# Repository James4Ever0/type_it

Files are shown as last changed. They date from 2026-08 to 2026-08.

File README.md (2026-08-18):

# Type It — Macro Keyboard

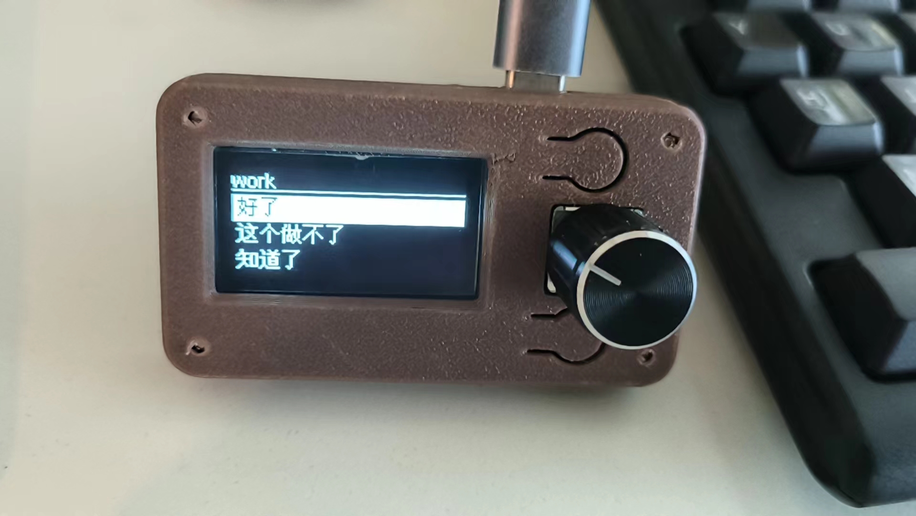
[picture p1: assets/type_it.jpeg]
Type It — Macro Keyboard


A pocket macro keyboard for the snippets you type over and over: chat replies,
work responses, template text. Turn the knob, pick a snippet, and it is sent —
as real USB HID keystrokes on the hardware, or straight to your clipboard in
the desktop demos.

Three interchangeable front-ends share one data model: a **profile** is a
`.txt` file whose non-empty lines are **candidates**, and everything re-sorts
by **most-recently-used**.

| Component | What it is | Docs |
|---|---|---|
| [`hardware/`](hardware/) | RP2040 Zero firmware + enclosure, types over USB HID | [hardware/README.md](hardware/README.md) |
| [`software/golang/`](software/golang/) | Go/Ebiten desktop demo → clipboard | [software/golang/README.md](software/golang/README.md) |
| [`software/python/`](software/python/) | pygame desktop demo → clipboard | [software/python/README.md](software/python/README.md) |

## Quick start

- **Hardware** — wire per [`hardware/WIRING.md`](hardware/WIRING.md), install
  the toolchain per [`hardware/DEPENDENCIES.md`](hardware/DEPENDENCIES.md),
  upload [`hardware/type_it/`](hardware/type_it/).
- **Go demo** — `cd software/golang && ./compile.sh && ./type_it`
- **Python demo** — `cd software/python && pip install -r requirements.txt && python main.py`

## Shared interaction model

- Turn the knob (or scroll) to move the highlight.
- Short-press to open a profile / type or copy a candidate.
- Long-press to go back.

## Repository layout

```text
.
├── hardware/              # RP2040 firmware, wiring, enclosure
│   ├── type_it/           # Arduino sketch
│   ├── casing/            # 3D-printable enclosure
│   ├── WIRING.md
│   └── DEPENDENCIES.md
├── software/
│   ├── golang/            # Ebiten desktop demo
│   └── python/            # pygame desktop demo
└── README.md
```

## License

Released into the public domain under the [Unlicense](https://unlicense.org).
See [`LICENSE`](LICENSE).

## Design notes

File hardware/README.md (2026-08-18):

# Type It Hardware — RP2040 Zero Macro Keyboard

A physical macro keyboard: a Waveshare **RP2040 Zero** running Arduino
firmware, a 1.3" **SH1106 128×64 I2C OLED**, and an **EC11 rotary encoder**
with push switch. Pick a profile, turn the knob, and the selected snippet is
typed into the focused application as real USB HID keystrokes.

It is the hardware counterpart of the desktop demos in
[`software/`](../software/) — all three share the same
profiles/candidates/recency model.

## Components

| Part | Role |
|---|---|
| Waveshare RP2040 Zero | MCU, USB HID keyboard |
| 1.3" SH1106 128×64 I2C OLED | Menu display, CJK-capable |
| EC11 rotary encoder | Scroll / confirm / long-press back |
| CON / BAK buttons | Optional confirm / back buttons |

## Repository layout

- [`type_it/`](type_it/) — Arduino sketch (`type_it/type_it.ino`)
- [`DEPENDENCIES.md`](DEPENDENCIES.md) — Arduino core + library install, board setup, upload
- [`WIRING.md`](WIRING.md) — GPIO pin map and step-by-step wiring guide
- [`casing/`](casing/) — 3D-printable enclosure (`.3mf`)
- [`assets/`](assets/) — wiring reference photo

## Quick start

1. Wire the module — see [`WIRING.md`](WIRING.md) (GPIO table, pull-ups,
   encoder direction, I2C address).
2. Install the toolchain — see [`DEPENDENCIES.md`](DEPENDENCIES.md).
3. Open `type_it/type_it.ino` and upload (Arduino IDE or `arduino-cli`).
4. Open the serial monitor at **115200 baud** and send `HELP` for the full
   command list.

## Firmware highlights

- **Profiles on LittleFS** — every `.txt` in `/profiles` is a profile; each
  non-empty line is a type-able candidate.
- **Recency ordering** — profiles and candidates re-sort by last use and the
  order survives reboots (stored in `/usage.dat`).
- **USB HID typing** — ASCII types directly; Unicode/CJK types per host
  method (Linux IBus, macOS Unicode Hex Input, Windows Alt+Numpad). Switch
  host behavior with `SETOS:lin|mac|win` or the Settings menu.
- **CJK display** — the SH1106 is rendered with the U8g2 `wqy12` GB2312 font.
- **Serial management** — create/rename/delete profiles and edit candidates
  over serial (`SETTEXT:profile <<EOF … EOF`, `APPEND`, `LIST`, …).
- **Diagnostics** — `DIAG` runs a 7-step self-test (display, encoder,
  buttons, OS typing, filesystem, EEPROM, font).
- **Resume state** — the last view and selection are restored from EEPROM on
  power-up.

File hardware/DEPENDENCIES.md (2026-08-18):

# Dependencies — Type It Macro Keyboard

## Required software

1. **Arduino IDE** 1.8.x or 2.x, or **Arduino CLI**
2. **Earle Philhower Arduino-Pico core** (supports RP2040/RP2350 boards with USB and LittleFS)
3. **U8g2 library** by Oliver Kraus (SH1106 display driver)

## Required hardware

- 1.3 Inch TFT OLED display with EC11 rotary encoder board (IIC interface)

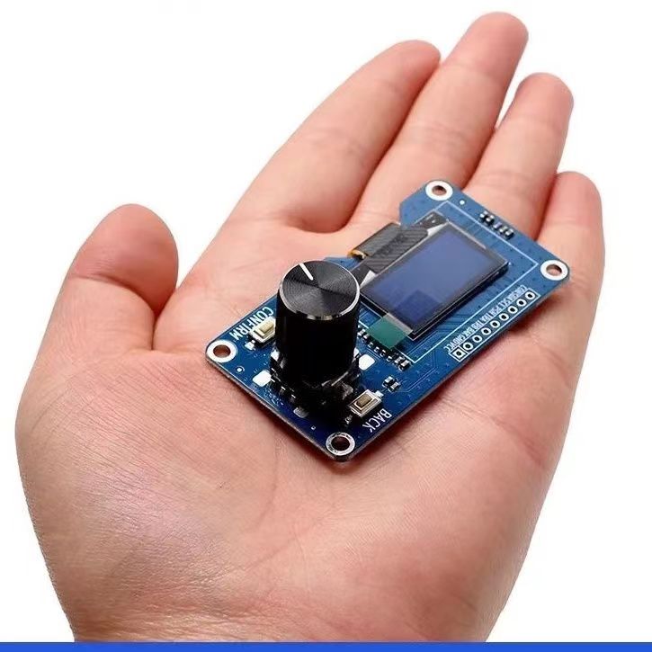
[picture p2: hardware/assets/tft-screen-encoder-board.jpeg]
TFT Screen Encoder Board (https://mobile.yangkeduo.com/goods.html?ps=Z3C52HupHn)


- RP2040-Zero microcontroller board

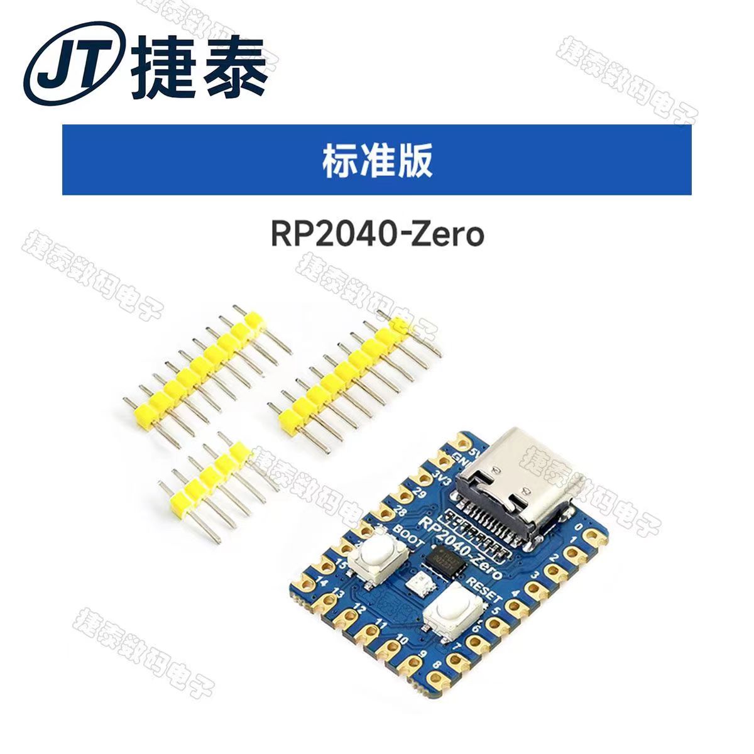
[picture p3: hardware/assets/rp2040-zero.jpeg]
RP2040-Zero (https://mobile.yangkeduo.com/goods.html?ps=jFZypVHLIi)


## Arduino-Pico core installation

### Arduino IDE 2.x

1. Open **File > Preferences**.
2. In **Additional boards manager URLs**, add:
   ```text
   https://github.com/earlephilhower/arduino-pico/releases/download/global/package_rp2040_index.json
   ```
3. Open **Tools > Board > Boards Manager**.
4. Search for **"Raspberry Pi Pico/RP2040"** by Earle F. Philhower, III.
5. Install the latest version.

### Arduino CLI

```bash
arduino-cli config add board_manager.additional_urls https://github.com/earlephilhower/arduino-pico/releases/download/global/package_rp2040_index.json
arduino-cli core update-index
arduino-cli core install rp2040:rp2040
```

## U8g2 library installation

### Arduino IDE

1. Open **Tools > Manage Libraries...**.
2. Search for **"U8g2"** by Oliver Kraus.
3. Install the latest version.

### Arduino CLI

```bash
arduino-cli lib install "U8g2"
```

## Board selection

Select the board that matches your hardware. For the Waveshare RP2040 Zero:

- **Board**: *Raspberry Pi Pico / RP2040 > Waveshare RP2040 Zero*
- **USB Stack**: *Adafruit TinyUSB* (recommended; required for `Keyboard.h` and USB-CDC Serial)
- **Flash Size**: choose a split that leaves room for a filesystem, e.g. *2 MB (Sketch: 1 MB, FS: 1 MB)* or larger

If your exact board is not listed, use **"Raspberry Pi Pico"** and set the correct USB stack and flash size.

## Build and upload

### Arduino IDE

1. Open `hardware_project/type_it/type_it.ino`.
2. Select the board and port as described above.
3. Click **Upload**.

### Arduino CLI

From the `hardware_project` directory:

```bash
arduino-cli compile --fqbn rp2040:rp2040:waveshare_rp2040_zero type_it
arduino-cli upload --fqbn rp2040:rp2040:waveshare_rp2040_zero -p /dev/ttyACM0 type_it
```

Replace `/dev/ttyACM0` with the actual serial port of your RP2040 Zero.

## First use

1. Open the **Serial Monitor** at **115200 baud**.
2. The firmware prints a startup banner and the number of stored profiles.
3. Type `HELP` and press Enter to see the available serial commands.

Example: create a profile and upload multiline text

```text
ADDPROFILE:work
OK created work

SETTEXT:work <<EOF
Hello, world!
Thanks,
Me
EOF
OK replaced work (29 bytes)

LIST
Profiles:
  work (3 items)
```

## Notes and limitations

- **HID typing**: `Keyboard.print()` sends raw keycodes. ASCII/Latin-1 text works reliably. Typing CJK or other multi-byte Unicode characters is not supported by the standard Arduino `Keyboard` library; such text can be stored and viewed on the display but will not type correctly through USB HID.
- **Display font**: The default font is `u8g2_font_7x14_tf` for the header and `u8g2_font_6x13_tf` for list items. If you need CJK glyphs on the display, replace these with a U8g2 CJK font (e.g., `u8g2_font_unifont_t_chinese2`) and note that the larger font may reduce the number of visible lines.
- **Filesystem wear**: Every type action writes the usage-order file to LittleFS. For heavy daily use, consider periodically backing up profiles via `VIEW:profile` and rebuilding the device rather than relying on the flash for indefinite high-frequency writes.

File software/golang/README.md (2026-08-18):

# Type It Go — Desktop Demo (Ebiten)

A Go/[Ebiten](https://ebitengine.org/) simulation of the macro keyboard: it
renders the LED display and knob, reads the same `./profiles` text files as
the firmware, and copies the selected candidate to the system clipboard.

## Requirements

- Go 1.22+
- Linux: X11 development headers (Ebiten dependency):

  ```bash
  sudo apt-get install -y libxrandr-dev libxcursor-dev libxinerama-dev libxi-dev libgl1-mesa-dev libxxf86vm-dev
  ```

## Build & run

```bash
./compile.sh     # checks X11 headers, go mod tidy, builds ./type_it
./type_it        # or: go run .
```

`./test.sh` runs `go vet`, builds, and — when `xvfb-run` is available —
smoke-runs the app headless for 2 seconds.

## Controls

| Input | Action |
|---|---|
| ↑ / W | Scroll up |
| ↓ / S | Scroll down |
| → / Enter / Space | Open profile / copy candidate |
| ← / Esc / Backspace | Go back |
| Q | Save & quit |
| Mouse wheel | Scroll |
| Drag on the knob | Scroll |
| Click on the knob | Press (long press = back) |

## Profiles

One profile = one `.txt` file in `./profiles/`. The file name is the profile
name; each non-empty, trimmed line is a candidate; duplicate lines are
collapsed.

```text
# profiles/work.txt
知道了
ok
这个做不了
```

Profiles and candidates are sorted most-recently-used first; the ordering is
persisted to `./usage.json` and restored on start.

## Files

- `main.go` — the entire demo (single file)
- `compile.sh`, `test.sh` — build / smoke-test helpers
- `profiles/` — user profile content
- `usage.json` — runtime state, regenerated automatically

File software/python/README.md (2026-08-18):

# Type It Python — Desktop Demo (pygame)

A [pygame](https://www.pygame.org/) simulation of the macro keyboard: it
renders the LED display and knob, reads the same `./profiles` text files as
the firmware, and copies the selected candidate to the clipboard.

## Requirements

- Python 3.10+
- Linux/X11: `wmctrl` (optional — keeps the window always-on-top)

## Install & run

```bash
pip install -r requirements.txt
python main.py
```

## Controls

| Input | Action |
|---|---|
| ↑ / W | Scroll up |
| ↓ / S | Scroll down |
| → / Enter / Space | Open profile / copy candidate |
| ← / Esc / Backspace | Go back |
| Q | Save & quit |
| Mouse wheel | Scroll |
| Drag on the knob | Scroll |
| Click on the knob | Press (long press = back) |

## Profiles

Same format as the Go demo and the firmware: one `.txt` file per profile in
`./profiles/`, each non-empty line is a candidate. Recency ordering **and**
the last-viewed UI state are persisted to `./usage.json` and restored on
start.

## Notes

- A CJK-capable system font is picked automatically for headers and list
  items, with a DejaVu fallback.
- On Linux the window is raised above others via `wmctrl` when available.

## Files

- `main.py` — the entire demo (single file)
- `requirements.txt` — pygame, pyperclip
- `profiles/` — user profile content
- `usage.json` — runtime state, regenerated automatically

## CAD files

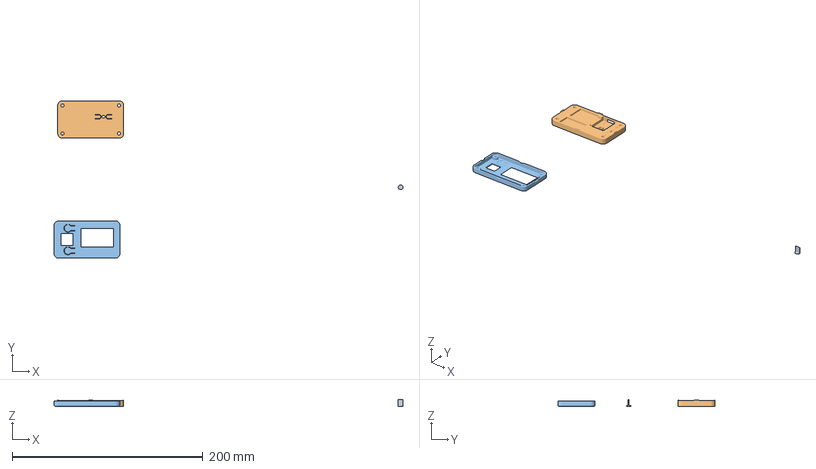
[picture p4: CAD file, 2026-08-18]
hardware/casing/ec11_rp2040_macro_keyboard_v2.3mf
365.6 x 165.0 x 7.00 mm
encoder_filter.stl
bottom_casing_with_wire_slot_and_screw_sink_v2_unfixed_fixed.stl_Boolean
Oled_EC11_Encoder_Case-Main.step_Boolean_Boolean_Boolean_Boolean

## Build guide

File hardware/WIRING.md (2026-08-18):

# Wiring Guide — Type It Macro Keyboard

This document describes how to connect the RP2040 Zero to the SH1106 I2C display + rotary encoder module described in `pinouts.txt`.

## Parts

- **MCU**: Waveshare RP2040 Zero (or any RP2040 board with the same GPIO labels)
- **Display / input module**: 1.3" SH1106 128×64 I2C OLED + EC11 rotary encoder + CON/BAK buttons
  - Connector labels from `pinouts.txt`: `CON, SDA, SCL, PSH, TRA, TRB, BAK, GND, VCC`
- **Breadboard and jumper wires** (or a custom PCB)

## Default GPIO mapping

The firmware uses the following RP2040 Zero GPIO pins by default. They are grouped together so you can use one side of the board for the whole module.

| Module pin | Function | RP2040 Zero GPIO | Note |
|---|---|---|---|
| VCC | 3.3 V power | 3V3 | Do **not** connect to 5 V |
| GND | Ground | GND | |
| SDA | I2C data | GP4 | `PIN_SDA` in `type_it.ino` |
| SCL | I2C clock | GP5 | `PIN_SCL` in `type_it.ino` |
| TRA | Encoder A phase | GP3 | `PIN_ENC_A` in `type_it.ino` |
| TRB | Encoder B phase | GP2 | `PIN_ENC_B` in `type_it.ino` |
| PSH | Encoder push switch | GP6 | `PIN_ENC_SW` in `type_it.ino` |
| CON | Confirm button | GP14 | `PIN_CON` in `type_it.ino` **(optional)** |
| BAK | Back button | GP15 | `PIN_BAK` in `type_it.ino` **(optional)** |

> The exact GPIO numbers are arbitrary — any digital GPIO can be used for the buttons and encoder, and any I2C-capable GPIO pair can be used for SDA/SCL. If you change the wiring, update the `#define PIN_...` lines at the top of `type_it/type_it.ino`.

## Minimal wiring (encoder push switch only)

If you only want the rotary encoder's built-in push switch and do not wire the separate `CON`/`BAK` buttons, change the top of `type_it.ino` to:

```cpp
#define PIN_CON   -1
#define PIN_BAK   -1
```

With this setup the encoder switch does everything:

| Action | How |
|---|-----|
| Confirm / open profile / type candidate | Short press the encoder knob |
| Go back | Long-press the encoder knob (> 600 ms) |

## Wiring tutorial

<!-- a picture showing actual wiring -->

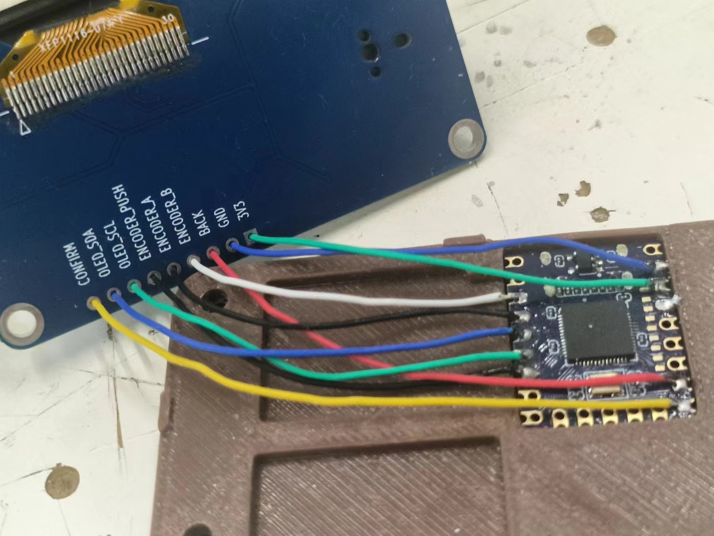
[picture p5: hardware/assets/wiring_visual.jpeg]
A picture showing actual wiring


Thin wires stripped from common data cabling are sufficient.

Step-by-step guide:

- Strip and pre-solder the wire coils before inserting them into the RP2040 solder holes.
- Optionally, use tape or heavy objects, or combine tape with thin plates, to hold the coils in place before soldering.
- Solder the coils onto the RP2040 board.
- Insert the coils into the corresponding holes on the display board.
- Pull the coils taut so the display board can be pushed down into place, close enough for the enclosure to be assembled.
- Use tape to hold the display in place.
- Cut off excess wire length, leaving at most 1 cm per wire.
- Use a soldering iron to heat the insulation of each wire and strip it off manually.
- Solder each wire into its corresponding hole on the display board.
- Trim any excess coil length.
- Remove the tape and assemble the enclosure.

## Pull-ups

- The firmware configures `INPUT_PULLUP` for all button and encoder pins. No external pull-up resistors are required for the switches or encoder A/B pins.
- The SH1106 module usually includes its own I2C pull-up resistors. If your module does not, add 4.7 kΩ pull-ups from SDA and SCL to 3.3 V.

## Encoder direction

If turning the knob clockwise moves the highlight **up** instead of **down**, swap the `PIN_ENC_A` and `PIN_ENC_B` definitions (or physically swap the `TRA` and `TRB` wires).

## I2C address

The default SH1106 I2C address is `0x3C`. If the display stays black after upload:

1. Check the module documentation for the correct address (some modules use `0x3D`).
2. If you need `0x3D`, change the U8g2 constructor in `type_it.ino` from:
   ```cpp
   U8G2_SH1106_128X64_NONAME_F_HW_I2C u8g2(U8G2_R0, U8G2_PIN_NONE);
   ```
   to:
   ```cpp
   U8G2_SH1106_128X64_NONAME_F_HW_I2C u8g2(U8G2_R0, U8G2_PIN_NONE, /* SCL */ PIN_SCL, /* SDA */ PIN_SDA, /* reset */ U8G2_PIN_NONE);
   u8g2.setI2CAddress(0x3D * 2);
   ```

## Physical layout tips

- Keep the I2C wires (SDA/SCL) short and twisted if possible to reduce noise.
- The encoder A/B wires can pick up noise; if you see erratic scrolling, add 100 nF ceramic capacitors from each encoder pin to GND, or reduce the wire length.
- The RP2040 Zero is 3.3 V only. Do not connect 5 V logic signals to the GPIO pins.

## Next steps

After wiring, follow `DEPENDENCIES.md` to install the required Arduino libraries and upload the firmware.

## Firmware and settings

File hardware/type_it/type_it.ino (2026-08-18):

/*
 * type_it — Macro Keyboard Firmware for RP2040 Zero
 *
 * A hardware port of ../main.py's profile/candidate macro keyboard.
 *
 * Hardware:
 *   - RP2040 Zero
 *   - 1.3" SH1106 128x64 I2C OLED
 *   - EC11 rotary encoder (TRA=A, TRB=B, PSH=push switch)
 *   - CON (KEY1) confirm button
 *   - BAK (KEYO) back button
 *
 * UX:
 *   - Encoder turn                    -> scroll highlight
 *   - Encoder short press / CON        -> open profile, select menu item, or type candidate
 *   - Encoder long press / BAK         -> go back; from Profiles opens the master menu
 *   - CON mirrors the encoder short press; BAK mirrors the encoder long press
 *   - Master menu (long press from Profiles):
 *       Profiles, Diagnostic, Settings, Stats, About, Help
 *   - Last-used ordering is persisted across reboots
 *
 * Serial commands (115200 baud, CRLF or LF terminated):
 *   SETTEXT:profile <<EOF     replace profile with a block of text
 *   APPENDTEXT:profile <<EOF  append a block of text to profile
 *   APPEND:profile text       append a single line to profile
 *   SETLINE:profile:n text    set/replace candidate at line n (1-based)
 *   ADDPROFILE:profile        create a new empty profile
 *   DELPROFILE:profile        delete a profile
 *   RENAME:old new            rename a profile
 *   DELLINE:profile:n         delete candidate at line n
 *   LIST                      list all profiles
 *   VIEW:profile              view profile contents
 *   INFO                      show version and state
 *   SETOS:lin|mac|win         set host OS for Unicode typing
 *   GETOS                     show current host OS
 *   DIAG                      enter interactive diagnostic mode
 *   HELP                      command summary
 *   RESET                     factory reset
 *
 * Heredoc-style markers are optional; if omitted, the literal string "EOF"
 * ends the upload (only useful for interactive terminals).
 */

#include <Keyboard.h>
#include <Wire.h>
#include <U8g2lib.h>
#include <LittleFS.h>
#include <EEPROM.h>
#include <vector>
#include <algorithm>
#include <cstring>
#include <cctype>

// ==================== Pin assignments (RP2040 Zero GPIO) ====================
#define PIN_SDA           4   // OLED SDA  (I2C0)
#define PIN_SCL           5   // OLED SCL  (I2C0)
#define PIN_ENC_A         3   // EC11 A phase (TRA)
#define PIN_ENC_B         2   // EC11 B phase (TRB)
#define PIN_ENC_SW        6   // EC11 push switch (PSH)
#define PIN_CON           14 // Confirm button (KEY1) — optional, set to -1 to disable
#define PIN_BAK          15   // Back button (KEYO) — optional, set to -1 to disable

// ==================== Constants ====================
#define FW_VERSION        0x02
#define EEPROM_SIZE       512
#define SERIAL_BAUD       115200
#define SERIAL_TIMEOUT_MS 1500

#define LONG_PRESS_MS     600
#define DEBOUNCE_MS       25
#define FLASH_MS          800
#define KNOB_STEP_MS      120   // minimum ms between highlight moves via encoder

#define ENCODER_PULSES_PER_DETENT 4
#define MAX_PROFILE_NAME  32
#define MAX_LINE_LEN      256
#define MAX_VISIBLE       3
#define HEADER_H          14
#define LINE_H            15
#define SCREEN_W          128
#define SCREEN_H          64

#define VERBOSE_SERIAL    1       // set to 0 to disable runtime Serial logging

#if VERBOSE_SERIAL
  #define DBG(x) do { if (VERBOSE_SERIAL) Serial.println(x); } while(0)
#else
  #define DBG(x)
#endif

// CJK font. Largest single-font Simplified Chinese coverage available in u8g2.
// Requires u8g2.drawUTF8() / u8g2.getUTF8Width() and u8g2.enableUTF8Print().
#define CJK_FONT u8g2_font_wqy12_t_gb2312

#define PROFILES_DIR      "/profiles"
#define USAGE_PATH        "/usage.dat"

// ==================== EEPROM layout ====================
#define ADDR_MAGIC        0
#define ADDR_VIEW         1
#define ADDR_PROF_IDX_LO  2
#define ADDR_PROF_IDX_HI  3
#define ADDR_CAND_IDX_LO  4
#define ADDR_CAND_IDX_HI  5
#define ADDR_OS_MODE      6
#define ADDR_RESERVED     7

// ==================== U8g2 display object ====================
U8G2_SH1106_128X64_NONAME_F_HW_I2C u8g2(U8G2_R0, U8X8_PIN_NONE);

// ==================== Data model ====================
struct Candidate {
  String text;
  uint32_t order;
};

struct Profile {
  String name;
  uint32_t order;
  std::vector<Candidate> candidates;
};

struct UsageEntry {
  char type;      // 'P' or 'C'
  String key;     // profile name OR "profile::candidate"
  uint32_t order;
};

// ==================== Runtime state ====================
std::vector<Profile> profiles;
std::vector<UsageEntry> usage;

String view = "profiles";       // "profiles" | "candidates" | "master" | "settings" | "stats" | "about" | "help"
int profileIndex = 0;
int candidateIndex = 0;
int masterIndex = 0;
int settingsIndex = 0;
int statsScroll = 0;
int helpScroll = 0;

// Scroll window offsets for cursor-based list scrolling
int profileListOffset = 0;
int candidateListOffset = 0;
int masterListOffset = 0;
int settingsListOffset = 0;
int statsListOffset = 0;
int helpListOffset = 0;

uint32_t nextOrder = 1;
bool needsRedraw = true;

// Host OS mode for Unicode typing
enum OSMode { OS_LIN = 0, OS_MAC = 1, OS_WIN = 2 };
const char* OSModeNames[] = {"lin", "mac", "win"};
OSMode osMode = OS_LIN;

// Diagnostic mode state
enum DiagState {
  DIAG_INTRO,
  DIAG_DISPLAY_TEST,
  DIAG_ENCODER_TEST,
  DIAG_BUTTON_TEST,
  DIAG_OS_TEST,
  DIAG_FILESYSTEM_TEST,
  DIAG_EEPROM_TEST,
  DIAG_FONT_TEST,
  DIAG_REPORT
};

struct DiagResult {
  String name;
  char status;      // 'P' = PASS, 'F' = FAIL, 'U' = UNKNOWN
  String detail;
};

bool inDiagnosticMode = false;
DiagState diagState = DIAG_INTRO;
int diagSelection = 0;                  // 0 = YES/CONTINUE, 1 = NO/SKIP

std::vector<DiagResult> diagResults;
std::vector<String> diagReportLines;
int diagReportScroll = 0;
int diagReportOffset = 0;

// Transient per-test state
int diagEncoderDetected = 0;            // +1 CW, -1 CCW, 0 none
uint8_t diagButtonStage = 0;            // 0=encoder switch, 1=CON, 2=BAK
bool diagButtonPhase = false;           // false=await press, true=confirm works
bool diagButtonConsumed = false;        // suppress short-press handling when press consumed as test input
bool diagButtonAnyFail = false;         // aggregate result across button test stages
uint8_t diagOsSubState = 0;             // 0=ask whether to type, 1=ask whether it typed correctly
bool diagFsOk = false;
bool diagEepromOk = false;

// Encoder state
volatile int encoderDelta = 0;
volatile uint8_t encoderState = 0;
const int8_t encoderTable[16] = {
  0, -1, 1, 0,
  1, 0, 0, -1,
  -1, 0, 0, 1,
  0, 1, -1, 0
};

// Button state
bool encPressed = false;
uint32_t encPressStart = 0;
bool longTriggered = false;

// Flash overlay
uint32_t flashUntil = 0;
String flashText = "";

// Upload state
enum UploadMode { UPLOAD_NONE, UPLOAD_SETTEXT, UPLOAD_APPENDTEXT };
UploadMode uploadMode = UPLOAD_NONE;
String uploadProfile = "";
String uploadMarker = "";
String uploadBuffer = "";

// ==================== Forward declarations ====================
void loadUsage();
void saveUsage();
uint32_t touchProfile(const String &name);
uint32_t touchCandidate(const String &profileName, const String &text);
uint32_t getProfileOrder(const String &name);
uint32_t getCandidateOrder(const String &profileName, const String &text);
void loadProfiles();
void loadCandidates(Profile &prof);
void saveProfileFile(const String &name, const String &content);
String readProfileFile(const String &name);
void appendProfileFile(const String &name, const String &content);
void deleteProfileFile(const String &name);
void renameProfileFile(const String &oldName, const String &newName);
bool profileExists(const String &name);
bool isValidProfileName(const String &name);
void splitLines(const String &content, std::vector<String> &out);
String joinLines(const std::vector<String> &lines);
void trimAndDedupLines(std::vector<String> &lines);

void draw();
void drawHeader(const String &title);
void drawList(const std::vector<String> &items, int selected, int &offset);
void flash(const String &text);

void handleSerial();
void processCommand(const String &cmd);
void beginUpload(UploadMode mode, const String &profile, const String &marker);
void handleUploadLine(const String &line);
bool isValidMarker(const String &marker);

void onEncoder();
void readButtons();
void moveHighlight(int delta);
void doShortPress();
void doBack();
void enterMasterMenu();
void handleMenuOrBack();
std::vector<String> buildStatsLines();
std::vector<String> buildHelpLines();
void typeCurrentCandidate();

void saveUIState();
void restoreUIState();
void initStorage();

// OS mode helpers
bool parseOSMode(const String &s, OSMode &out);
const char* osModeName(OSMode mode);

// UTF-8 utilities
bool utf8DecodeNext(const String &s, unsigned &idx, uint32_t &outCodePoint);
String utf8EncodeCodePoint(uint32_t cp);
unsigned utf8CodePointCount(const String &s);
String utf8SubstringByChars(const String &s, unsigned charStart, unsigned charCount);
String utf8CropChars(const String &s, unsigned maxChars);
String utf8CropPixels(const String &s, u8g2_uint_t maxWidth);

// Unicode typing
String toHexLower(uint32_t value, int digits);
void typeCodePoint(uint32_t cp);
void typeUnicode(const String &text);

// Diagnostic mode
void enterDiagnosticMode();
void exitDiagnosticMode();
void diagGotoState(DiagState next);
void diagHandleEncoder(int steps);
void diagHandleShortPress();
void diagHandleLongPress();
void diagCaptureButtonPress(int id);
void diagRecordResult(const String &name, char status, const String &detail = "");
void diagRunFilesystemTest();
void diagRunEepromTest();
void diagBuildReport();
void diagPrintReport();
void drawDiagnostic();

// ==================== Setup ====================
void setup() {
  // Pin setup
  pinMode(PIN_ENC_A, INPUT_PULLUP);
  pinMode(PIN_ENC_B, INPUT_PULLUP);
  pinMode(PIN_ENC_SW, INPUT_PULLUP);
  if (PIN_CON >= 0) pinMode(PIN_CON, INPUT_PULLUP);
  if (PIN_BAK >= 0) pinMode(PIN_BAK, INPUT_PULLUP);

  // Initialize encoder state so the first transition is decoded correctly.
  encoderState = (digitalRead(PIN_ENC_A) << 1) | digitalRead(PIN_ENC_B);

  attachInterrupt(digitalPinToInterrupt(PIN_ENC_A), onEncoder, CHANGE);
  attachInterrupt(digitalPinToInterrupt(PIN_ENC_B), onEncoder, CHANGE);

  // Display
  Wire.setSDA(PIN_SDA);
  Wire.setSCL(PIN_SCL);
  u8g2.setBusClock(400000);
  u8g2.begin();
  u8g2.enableUTF8Print();
  u8g2.setFont(CJK_FONT);
  u8g2.setContrast(128);

  // Filesystem
  if (!LittleFS.begin()) {
    DBG("[FS] LittleFS.begin() failed, formatting...");
    LittleFS.format();
    LittleFS.begin();
  }
  DBG("[FS] LittleFS started");

  // EEPROM
  EEPROM.begin(EEPROM_SIZE);
  initStorage();

  // Keyboard
  Keyboard.begin();

  // Serial
  Serial.begin(SERIAL_BAUD);
  unsigned long serialTimeout = millis() + SERIAL_TIMEOUT_MS;
  while (!Serial && millis() < serialTimeout) { delay(10); }

  loadUsage();
  loadProfiles();
  restoreUIState();

  Serial.println("=== type_it macro keyboard ===");
  Serial.println("Profiles: " + String(profiles.size()));
  Serial.println("OS mode: " + String(osModeName(osMode)));
  Serial.println("Send HELP for commands.");
}

// ==================== Main loop ====================
void loop() {
  handleSerial();
  readButtons();

  // Encoder navigation
  noInterrupts();
  int delta = encoderDelta;
  encoderDelta = 0;
  interrupts();

  if (inDiagnosticMode) {
    static int diagEncoderAccum = 0;
    static uint32_t diagLastStepMs = 0;
    if (delta != 0) {
      diagEncoderAccum += delta;
      uint32_t now = millis();
      if (abs(diagEncoderAccum) >= ENCODER_PULSES_PER_DETENT && now - diagLastStepMs >= KNOB_STEP_MS) {
        int steps = diagEncoderAccum / ENCODER_PULSES_PER_DETENT;
        diagEncoderAccum -= steps * ENCODER_PULSES_PER_DETENT;
        diagHandleEncoder(steps);
        diagLastStepMs = now;
      }
    }
  } else {
    static int encoderAccum = 0;
    static uint32_t lastStepMs = 0;
    if (delta != 0) {
      encoderAccum += delta;
      uint32_t now = millis();
      if (abs(encoderAccum) >= ENCODER_PULSES_PER_DETENT && now - lastStepMs >= KNOB_STEP_MS) {
        int steps = encoderAccum / ENCODER_PULSES_PER_DETENT;
        encoderAccum -= steps * ENCODER_PULSES_PER_DETENT;
        moveHighlight(steps);
        lastStepMs = now;
      }
    }
  }

  // Draw at ~30 FPS so flash overlays expire cleanly
  static uint32_t lastDrawMs = 0;
  uint32_t now = millis();
  if (needsRedraw || now - lastDrawMs >= 33) {
    draw();
    lastDrawMs = now;
    needsRedraw = false;
  }

  delay(1);
}

// ==================== Encoder ISR ====================
void onEncoder() {
  uint8_t a = digitalRead(PIN_ENC_A);
  uint8_t b = digitalRead(PIN_ENC_B);
  uint8_t state = (a << 1) | b;
  uint8_t idx = (encoderState << 2) | state;
  encoderDelta += encoderTable[idx];
  encoderState = state;
}

// ==================== Button handling ====================
void readButtons() {
  uint32_t now = millis();

  // Encoder switch (active low)
  static bool lastEnc = HIGH;
  static uint32_t lastEncChange = 0;
  bool curEnc = digitalRead(PIN_ENC_SW);
  if (curEnc != lastEnc && now - lastEncChange > DEBOUNCE_MS) {
    lastEnc = curEnc;
    lastEncChange = now;
    if (curEnc == LOW) {
      encPressed = true;
      encPressStart = now;
      longTriggered = false;
      diagButtonConsumed = false;
      if (inDiagnosticMode && diagState == DIAG_BUTTON_TEST && !diagButtonPhase && diagButtonStage == 0) {
        diagCaptureButtonPress(0);
        diagButtonConsumed = true;
      }
      DBG("[BTN] encoder press");
    } else {
      if (encPressed && !longTriggered && now - encPressStart < LONG_PRESS_MS) {
        if (diagButtonConsumed) {
          diagButtonConsumed = false;
          DBG("[BTN] encoder release (consumed)");
        } else if (inDiagnosticMode) {
          DBG("[BTN] encoder release (short)");
          diagHandleShortPress();
        } else {
          DBG("[BTN] encoder release (short)");
          doShortPress();
        }
      } else if (encPressed && longTriggered) {
        DBG("[BTN] encoder release (after long)");
      }
      encPressed = false;
    }
  }

  // Long press detection for encoder switch
  if (encPressed && !longTriggered && (millis() - encPressStart >= LONG_PRESS_MS)) {
    longTriggered = true;
    DBG("[BTN] encoder long press");
    handleMenuOrBack();
  }

  // CON button
  if (PIN_CON >= 0) {
    static bool lastCon = HIGH;
    static uint32_t lastConChange = 0;
    bool curCon = digitalRead(PIN_CON);
    if (curCon != lastCon && now - lastConChange > DEBOUNCE_MS) {
      lastCon = curCon;
      lastConChange = now;
      if (curCon == LOW) {
        DBG("[BTN] CON press");
        if (inDiagnosticMode && diagState == DIAG_BUTTON_TEST && !diagButtonPhase && diagButtonStage == 1) {
          diagCaptureButtonPress(1);
        } else if (inDiagnosticMode) {
          diagHandleShortPress();
        } else {
          doShortPress();
        }
      }
    }
  }

  // BAK button — acts like a long press of the encoder switch: fires
  // handleMenuOrBack() immediately on press. In the diagnostic button test
  // it is captured as the BAK key being tested.
  if (PIN_BAK >= 0) {
    static bool lastBak = HIGH;
    static uint32_t lastBakChange = 0;
    bool curBak = digitalRead(PIN_BAK);
    if (curBak != lastBak && now - lastBakChange > DEBOUNCE_MS) {
      lastBak = curBak;
      lastBakChange = now;
      if (curBak == LOW) {
        DBG("[BTN] BAK press (menu/back)");
        if (inDiagnosticMode && diagState == DIAG_BUTTON_TEST && !diagButtonPhase && diagButtonStage == 2) {
          diagCaptureButtonPress(2);
        } else {
          handleMenuOrBack();
        }
      }
    }
  }
}

// ==================== Navigation actions ====================
void moveHighlight(int delta) {
  if (delta == 0) return;
  if (view == "profiles") {
    if (profiles.empty()) return;
    profileIndex = (profileIndex + delta + profiles.size()) % profiles.size();
    candidateIndex = 0;
    DBG("[UI] scroll profiles delta=" + String(delta) + " idx=" + String(profileIndex));
  } else if (view == "candidates") {
    if (profileIndex < 0 || profileIndex >= (int)profiles.size()) return;
    auto &cands = profiles[profileIndex].candidates;
    if (cands.empty()) return;
    candidateIndex = (candidateIndex + delta + cands.size()) % cands.size();
    DBG("[UI] scroll candidates delta=" + String(delta) + " idx=" + String(candidateIndex));
  } else if (view == "master") {
    const int MASTER_ITEMS = 6;
    masterIndex = (masterIndex + delta + MASTER_ITEMS) % MASTER_ITEMS;
    DBG("[UI] scroll master delta=" + String(delta) + " idx=" + String(masterIndex));
  } else if (view == "settings") {
    const int OS_ITEMS = 3;
    settingsIndex = (settingsIndex + delta + OS_ITEMS) % OS_ITEMS;
    DBG("[UI] scroll settings delta=" + String(delta) + " idx=" + String(settingsIndex));
  } else if (view == "stats") {
    std::vector<String> lines = buildStatsLines();
    int maxScroll = max(0, (int)lines.size() - 1);
    statsScroll = constrain(statsScroll + delta, 0, maxScroll);
    DBG("[UI] scroll stats delta=" + String(delta) + " idx=" + String(statsScroll));
  } else if (view == "help") {
    std::vector<String> lines = buildHelpLines();
    int maxScroll = max(0, (int)lines.size() - 1);
    helpScroll = constrain(helpScroll + delta, 0, maxScroll);
    DBG("[UI] scroll help delta=" + String(delta) + " idx=" + String(helpScroll));
  } else if (view == "about") {
    // static page, no scrolling
  }
  saveUIState();
  needsRedraw = true;
}

void doShortPress() {
  if (view == "profiles") {
    if (profileIndex >= 0 && profileIndex < (int)profiles.size()) {
      String name = profiles[profileIndex].name;
      DBG("[UI] short press: opening profile '" + name + "'");
      touchProfile(name);
      loadProfiles();              // re-sort
      profileIndex = 0;
      for (size_t i = 0; i < profiles.size(); i++) {
        if (profiles[i].name == name) {
          profileIndex = i;
          break;
        }
      }
      view = "candidates";
      loadCandidates(profiles[profileIndex]);  // ensure candidates are loaded now that view is candidates
      candidateIndex = 0;
      saveUIState();
      DBG("[UI] entered candidates view for '" + name + "', " + String(profiles[profileIndex].candidates.size()) + " item(s)");
      needsRedraw = true;
    }
  } else if (view == "candidates") {
    typeCurrentCandidate();
  } else if (view == "master") {
    switch (masterIndex) {
      case 0:
        view = "profiles";
        DBG("[UI] master: Profiles");
        break;
      case 1:
        DBG("[UI] master: Diagnostic");
        enterDiagnosticMode();
        return;  // diagnostic mode takes over; don't touch view/needsRedraw here
      case 2:
        view = "settings";
        settingsIndex = (int)osMode;
        DBG("[UI] master: Settings");
        break;
      case 3:
        view = "stats";
        statsScroll = 0;
        DBG("[UI] master: Stats");
        break;
      case 4:
        view = "about";
        DBG("[UI] master: About");
        break;
      case 5:
        view = "help";
        helpScroll = 0;
        DBG("[UI] master: Help");
        break;
    }
    saveUIState();
    needsRedraw = true;
  } else if (view == "settings") {
    OSMode newMode = (OSMode)settingsIndex;
    if (newMode != osMode) {
      osMode = newMode;
      saveUIState();
      flash("OS: " + String(osModeName(osMode)));
    }
    view = "master";
    saveUIState();
    needsRedraw = true;
  } else if (view == "stats" || view == "about" || view == "help") {
    view = "master";
    saveUIState();
    needsRedraw = true;
  }
}

void doBack() {
  if (view == "candidates") {
    view = "profiles";
    candidateIndex = 0;
    DBG("[UI] back: returning to profiles");
  } else if (view == "settings" || view == "stats" || view == "about" || view == "help") {
    view = "master";
    DBG("[UI] back: returning to master");
  } else if (view == "master") {
    view = "profiles";
    masterIndex = 0;
    DBG("[UI] back: returning to profiles from master");
  }
  saveUIState();
  needsRedraw = true;
}

void enterMasterMenu() {
  view = "master";
  saveUIState();
  needsRedraw = true;
  DBG("[UI] entered master menu");
}

// The action bound to an encoder long press. CON/BAK buttons map onto the
// encoder behaviors: CON = encoder short press (doShortPress), BAK = encoder
// long press (this function). From Profiles it opens the master menu, from
// elsewhere it goes back; during diagnostics it aborts.
void handleMenuOrBack() {
  if (inDiagnosticMode) {
    diagHandleLongPress();
  } else if (view == "profiles") {
    enterMasterMenu();
  } else {
    doBack();
  }
}

size_t computeTxtBytesInDir(const String &path) {
  size_t total = 0;
  File dir = LittleFS.open(path.c_str(), "r");
  if (!dir || !dir.isDirectory()) {
    if (dir) dir.close();
    return total;
  }
  File f = dir.openNextFile();
  while (f) {
    String name = f.name();
    if (!name.startsWith("/")) name = path + (path.endsWith("/") ? "" : "/") + name;
    if (name.endsWith(".txt")) {
      total += f.size();
    } else if (f.isDirectory()) {
      total += computeTxtBytesInDir(name);
    }
    f.close();
    f = dir.openNextFile();
  }
  return total;
}

size_t computeStoredBytes() {
  size_t total = 0;
  if (LittleFS.exists(USAGE_PATH)) {
    File f = LittleFS.open(USAGE_PATH, "r");
    if (f) {
      total += f.size();
      f.close();
    }
  }
  total += computeTxtBytesInDir("/");
  return total;
}
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
